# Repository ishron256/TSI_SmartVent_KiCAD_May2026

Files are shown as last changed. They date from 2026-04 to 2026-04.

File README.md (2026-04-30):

# TSI SmartVent — KiCAD Design Documents (May 2026)

This repository contains the KiCAD design documents for the **TSI SmartVent** project.  
All schematics, PCB layouts, libraries, and fabrication outputs are stored here and will be regularly updated.

---

## Repository Structure

```
TSI_SmartVent_KiCAD_May2026/
├── Schematic/       # KiCAD schematic files (.kicad_sch, .kicad_pro)
├── PCBLayout/       # KiCAD PCB layout files (.kicad_pcb)
├── Libraries/       # Custom symbol and footprint libraries
│   ├── Symbols/     # Custom schematic symbols (.kicad_sym)
│   └── Footprints/  # Custom PCB footprints (.pretty/)
└── Outputs/         # Fabrication outputs
    ├── Gerbers/     # Gerber files for PCB manufacturing
    ├── BOM/         # Bill of Materials
    └── PDF/         # PDF exports of schematics and layouts
```

---

## Getting Started

1. Install [KiCAD 8.x](https://www.kicad.org/download/) or later.
2. Clone this repository:
   ```bash
   git clone https://github.com/ishron256/TSI_SmartVent_KiCAD_May2026.git
   ```
3. Open the project file (`.kicad_pro`) in `Schematic/` with KiCAD.

---

## Contribution Guidelines

- Commit schematic and layout changes together where possible.
- Export updated Gerbers and BOM to `Outputs/` whenever a design revision is finalized.
- Use descriptive commit messages referencing the design revision (e.g., `Rev A – added power stage schematic`).
- Do **not** commit KiCAD auto-save or backup files (`*.kicad_sch-bak`, `_autosave-*`).

---

## License

© TSI — All rights reserved.

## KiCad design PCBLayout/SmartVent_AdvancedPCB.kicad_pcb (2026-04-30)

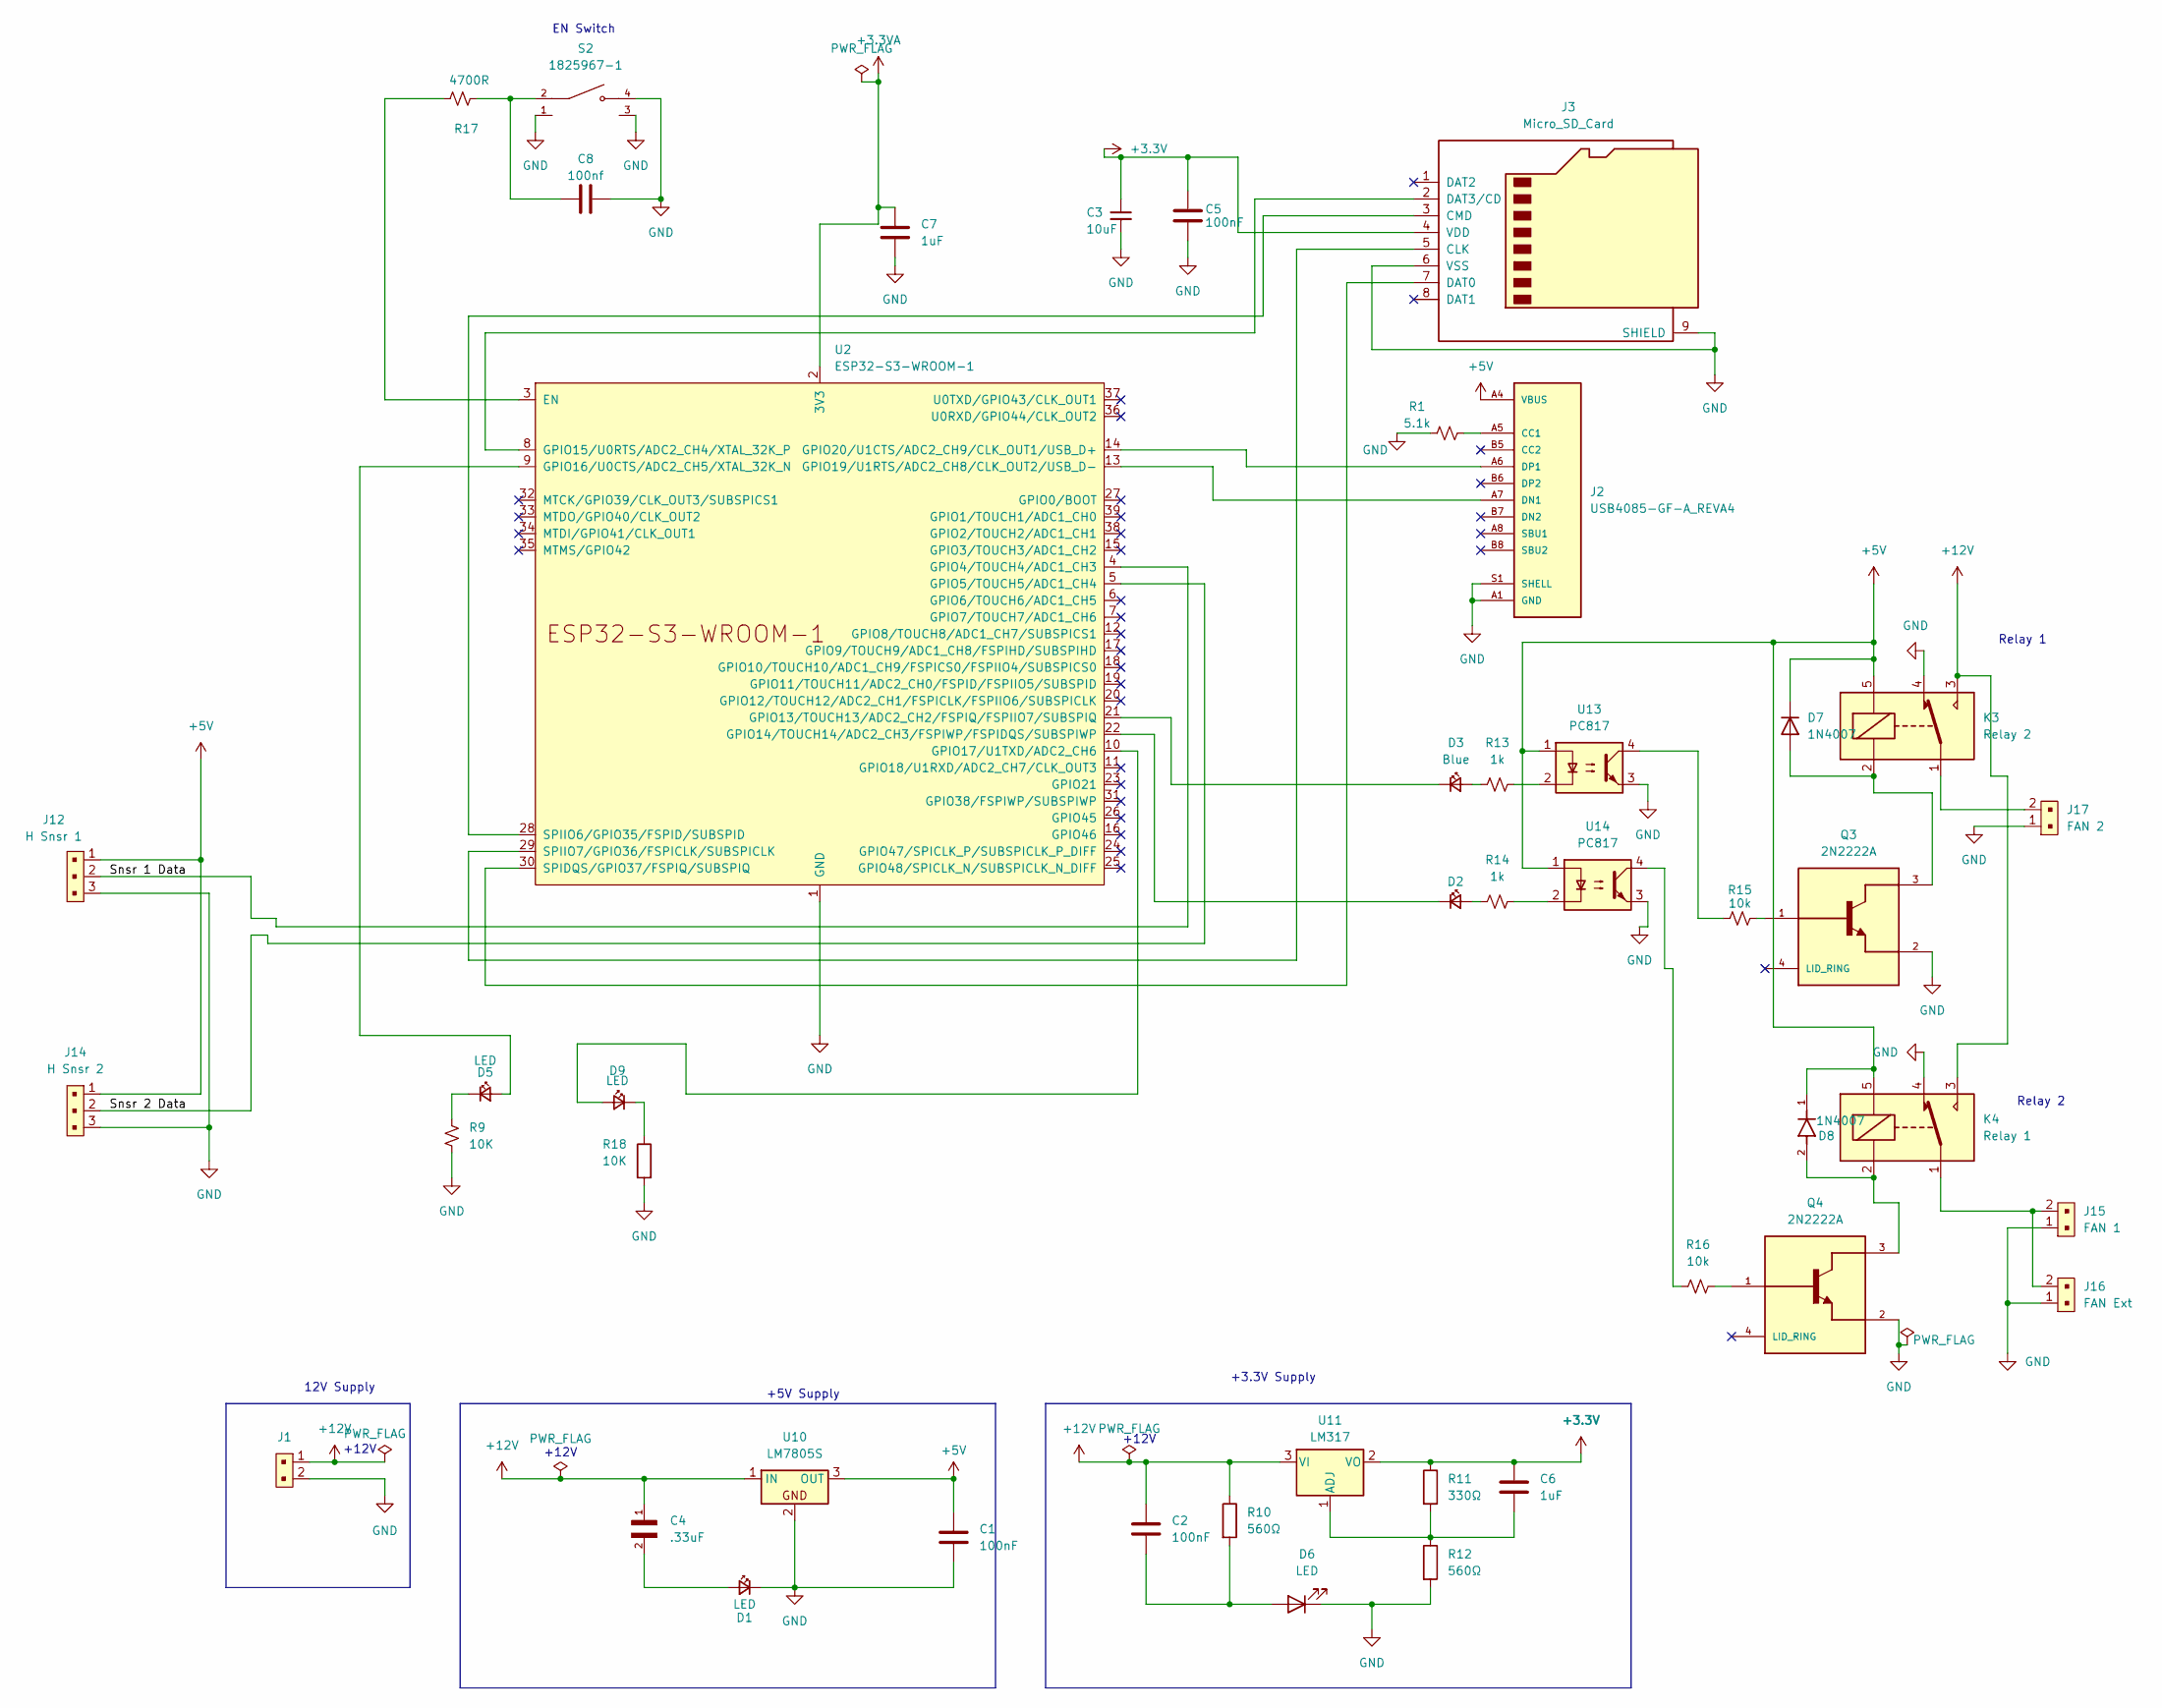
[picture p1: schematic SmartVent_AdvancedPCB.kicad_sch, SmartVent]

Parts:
C1, C2, C5: 100nF; SmartVent_Footprint_Capacitor_SMDC_0603_1608Metric_Kyocera_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
C3: 10uF; SmartVent_Footprints_C_0603_1608Metric_AVX_06033C103KAT2A; Voltage 6.3V; Tolerance 20%
C4: .33uF; SmartVent_Footprint_CAPC1608X90N_Kemet
C6, C7: 1uF; SmartVent_Footprint_C_0603_1608Metric_Yageo_CC0603MRX5R6BB1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
C8: 100nf; SmartVent_Footprint_Capacitor_SMDC_0603_1608Metric_Kyocera_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
D1, D6: LED; SmartVent_Footprint_LED_0603_1608Metric_Rohm_Green_SML-D12P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
D2, D3: Blue; SmartVent_Footprint_LED_0603_1608MetriRohm_Blue_SMLE12BC7TT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
D5, D9: LED; SmartVent_Footprint_LED_0603_1608Metric_Rohm_Red_SML-E12V8W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
D7: 1N4007; D_SOD-123F
D8: 1N4007; SmartVent_Footprint_D_SOD-123F_EIC_1n4007; PARTREV C
J1: 2 Pin Conn; JST_XH_B2B-XH-AM_1x02_P2.50mm_Vertical; MPN B2B-XH-A(LF)(SN); Digi-Key_PN 455-2247-ND
J2: USB4085-GF-A_REVA4; GCT_USB4085-GF-A_REVA4; PARTREV A4
J3: Micro_SD_Card; SmartVent_Footprint_microSD_HC_Wuerth_693072010801
J12: H Snsr 1; JST_XH_B3B-XH-A_1x03_P2.50mm_Vertical; MPN B3B-XH-A(LF)(SN); Digi-Key_PN 455-2248-ND
J14: H Snsr 2; JST_XH_B3B-XH-A_1x03_P2.50mm_Vertical; MPN B3B-XH-A(LF)(SN); Digi-Key_PN 455-2248-ND
J15: FAN 1; JST_XH_B2B-XH-A_1x02_P2.50mm_Vertical; MPN B2B-XH-A(LF)(SN); Digi-Key_PN 455-2247-ND
J16: FAN Ext; JST_XH_B2B-XH-A_1x02_P2.50mm_Vertical; MPN B2B-XH-A(LF)(SN); Digi-Key_PN 455-2247-ND
J17: FAN 2; JST_XH_B2B-XH-AM_1x02_P2.50mm_Vertical; MPN B2B-XH-A(LF)(SN); Digi-Key_PN 455-2247-ND
K3: Relay 2; SmartVent_Footprint_Relay_SPDT_SANYOU_SRD_Series_Form_C
K4: Relay 1; SmartVent_Footprint_Relay_SPDT_SANYOU_SRD_Series_Form_C
Q3, Q4: 2N2222A; SmartVent_Footprint_TRANS_2N2222AUBC; PARTREV 2
R1: 5.1k; R_0603_1608Metric
R9: 10K; R_0603_1608Metric_Pad0.98x0.95mm
R10, R12: 560Ω; R_0603_1608Metric_Pad0.98x0.95mm
R11: 330Ω; R_0603_1608Metric_Pad0.98x0.95mm
R13: 1k; R_0603_1608Metric
R14: 1k; SmartVent_Footprint_R_0201_0603Metric
R15, R16: 10k; R_0603_1608Metric_Pad0.98x0.95mm
R17: 4700R; R_0603_1608Metric_Pad0.98x0.95mm
R18: 10K; R_0603_1608Metric
S2: 1825967-1; SmartVent_Footprint_S2_SW_1825967-1; PARTREV E
U2: ESP32-S3-WROOM-1
U10: LM7805S; SmartVent_Footprint_U10_SOT-223-3_TabPin2; DigiKey_Part_Number 296-44520-1-ND
U11: LM317; SmartVent_Footprint_U11_SOT-223-3_TabPin2
U13, U14: PC817; SmartVent_Footprint_U13_U14_SOP254P975X460-4N

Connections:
+3.3V: C3.1, C5.1, C6.1, J3.4 (VDD), R11.1, U11.2 (VO)
+3.3VA: C7.1, U2.2 (3V3)
+5V: C1.1, D7.1 (K), D8.1, J2.A4 (VBUS), J2.A9 (VBUS), J2.B4 (VBUS), J2.B9 (VBUS), J12.1, J14.1, K3.5, K4.5, U10.3 (OUT), U13.1, U14.1
+12V: C2.1, C4.1, J1.1, K3.3, K4.3, R10.1, U10.1 (IN), U11.3 (VI)
/Snsr 1 Data: J12.2, U2.4 (GPIO4/TOUCH4/ADC1_CH3)
/Snsr 2 Data: J14.2, U2.5 (GPIO5/TOUCH5/ADC1_CH4)
GND: C1.2, C3.2, C5.2, C7.2, C8.1, D1.1 (K), D6.1 (K), J1.2, J2.A1 (GND), J2.A12 (GND), J2.B1 (GND), J2.B12 (GND), J2.S1 (SHELL), J2.S2 (SHELL), J2.S3 (SHELL), J2.S4 (SHELL), J3.6 (VSS), J3.9 (SHIELD), J12.3, J14.3, J15.1, J16.1, J17.1, K3.4, K4.4, Q3.2, Q4.2, R1.1, R9.2, R12.2, R18.2, S2.1, S2.3, S2.4, U2.1 (GND), U2.40 (GND), U2.41 (GND), U10.2, U13.3, U14.3
unnamed: C8.2, R17.1, S2.2
unnamed: C4.2, D1.2 (A)
unnamed: D2.2 (A), R14.2
unnamed: D2.1 (K), U2.22 (GPIO14/TOUCH14/ADC2_CH3/FSPIWP/FSPIDQS/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)
unnamed: D3.2 (A), R13.2
unnamed: D3.1 (K), U2.21 (GPIO13/TOUCH13/ADC2_CH2/FSPIQ/FSPIIO7/S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)
unnamed: D5.2 (A), U2.9 (GPIO16/U0CTS/ADC2_CH5/XTAL_32K_N)
unnamed: D5.1 (K), R9.1
unnamed: C2.2, D6.2 (A), R10.2
unnamed: D7.2 (A), K3.2, Q3.3
unnamed: D8.2, K4.2, Q4.3
unnamed: D9.2 (A), U2.10 (GPIO17/U1TXD/ADC2_CH6)
unnamed: D9.1 (K), R18.1
unnamed: J2.A5 (CC1), R1.2
unnamed: J2.A7 (DN1), U2.13 (GPIO19/U1RTS/ADC2_CH8/CLK_OUT2/USB_D-)
unnamed: J2.A6 (DP1), U2.14 (GPIO20/U1CTS/ADC2_CH9/CLK_OUT1/USB_D+)
unnamed: J3.5 (CLK), U2.29 (SPIIO7/GPIO36/FSPICLK/SUBSPICLK)
unnamed: J3.3 (CMD), U2.28 (SPIIO6/GPIO35/FSPID/SUBSPID)
unnamed: J3.7 (DAT0), U2.30 (SPIDQS/GPIO37/FSPIQ/SUBSPIQ)
unnamed: J3.2 (DAT3/CD), U2.8 (GPIO15/U0RTS/ADC2_CH4/XTAL_32K_P)
unnamed: J15.2, J16.2, K4.1
unnamed: J17.2, K3.1
unnamed: Q3.1, R15.1
unnamed: Q4.1, R16.1
unnamed: R13.1, U13.2
unnamed: R14.1, U14.2
unnamed: R15.2, U13.4
unnamed: R16.2, U14.4
unnamed: R17.2, U2.3 (EN)
unnamed: C6.2, R11.2, R12.1, U11.1 (ADJ)

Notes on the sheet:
12V Supply
Relay 2
EN Switch
Relay 1
+12V
+5V Supply
+12V
+3.3V Supply

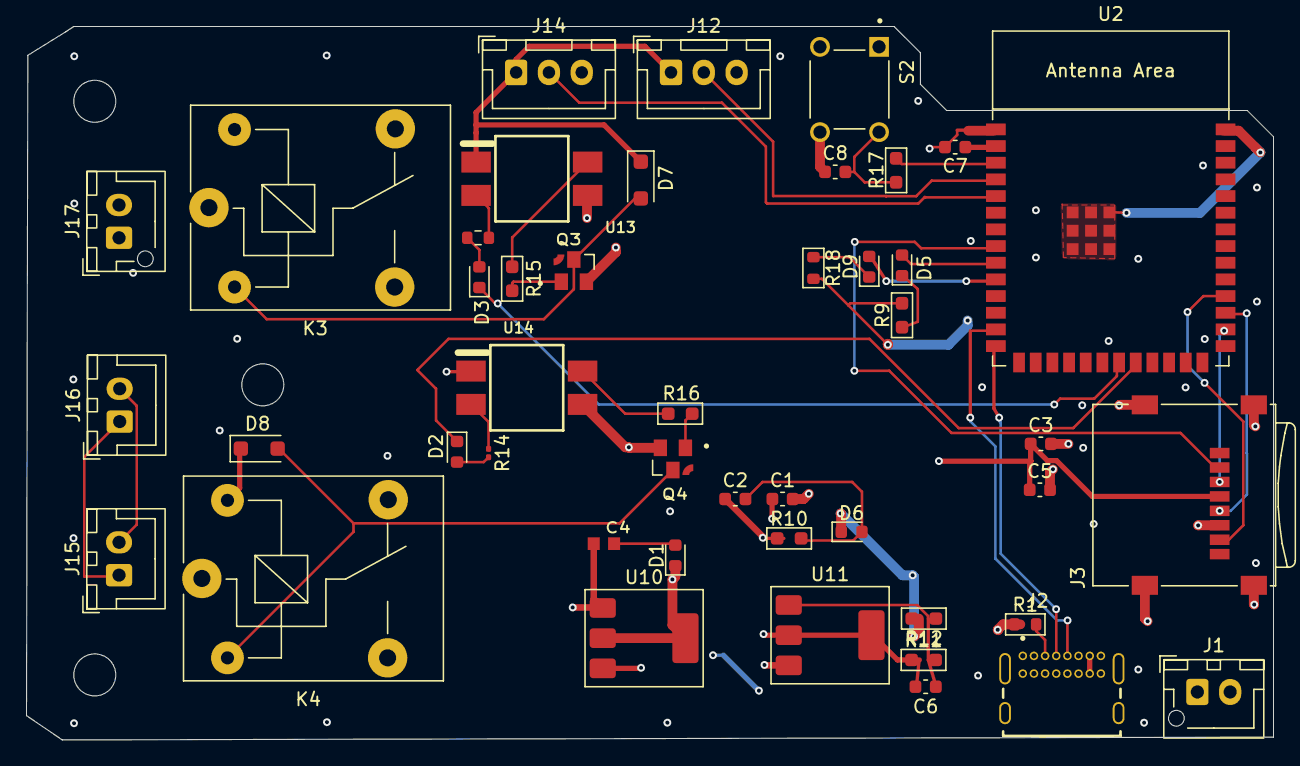
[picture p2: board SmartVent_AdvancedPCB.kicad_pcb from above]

Board: 4 copper layers, 95.0 x 54.4 mm, 45 parts (0 on the bottom side), 37 nets.

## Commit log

2026-04-30 Set up KiCAD project structure: README, .gitignore, and directory scaffold
    Agent-Logs-Url: https://github.com/ishron256/TSI_SmartVent_KiCAD_May2026/sessions/a3ef05f6-81e2-4876-b4a5-14bccbbf3feb
2026-04-30 New Version Control Enabled
    Initial Commit of the project files that I have been working on.
    [SmartVent_AdvancedPCB.kicad_pcb, SmartVent_AdvancedPCB.kicad_sch]
